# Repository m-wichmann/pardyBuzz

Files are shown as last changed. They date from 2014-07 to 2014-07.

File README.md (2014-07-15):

# pardyBuzz
This is a little hardware, that attaches a button to USB using an ATtiny. Instead of hardware USB this project uses the software USB stack V-USB [1]. Basically the whole project is based on the info from the V-USB site.

This project is developed as input for the pyPardy project [2].

# License
The firmware is licensed under GPLv3. The hardware is licensed under TAPR Open Hardware License.

[1] http://www.obdev.at/vusb/
[2] https://github.com/wichmann/pyPardy

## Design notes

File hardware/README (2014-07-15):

# pardyBuzz Hardware
This is a simple PCB that contains a ATtiny and the USB interface. A button should be soldered to the PB2 pin, since thats the interrupt pin.

# BOM
* 1x ATtiny25/45/85 (tested with ATtiny85)
* 1x 100 nF
* 2x 68 Ohm
* 1x 1.5K Ohm
* 2x 3.6 V Zener Diode

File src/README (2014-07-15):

# pardyBuzz Firmware
This firmware basically just uses the V-USB stack and the INT0 Interrupt.

The buzzer implements a USB control endpoint, as well as an interrupt endpoint. The control endpoint is used to get and set the device id (bRequest == 0). Reading of the device id is done by sending the parameter 0x00. Every other value sets the id to that value. The interrupt endpoint is used to signal a button push. Everytime the button interrupt occurs, the byte 0xa5 is send over this endpoint. Debouncing is not done in the firmware.

Since the internal oscillator is used, calibration is used to optimize the USB timing. The function 'calibrateOscillator' is taken from some V-USB sample projects.

# EEPROM
1   -> Oscillator calibration
2   -> Device ID

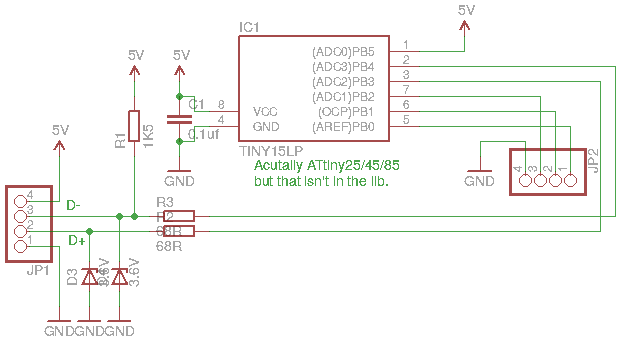
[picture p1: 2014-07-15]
hardware/circuit.png

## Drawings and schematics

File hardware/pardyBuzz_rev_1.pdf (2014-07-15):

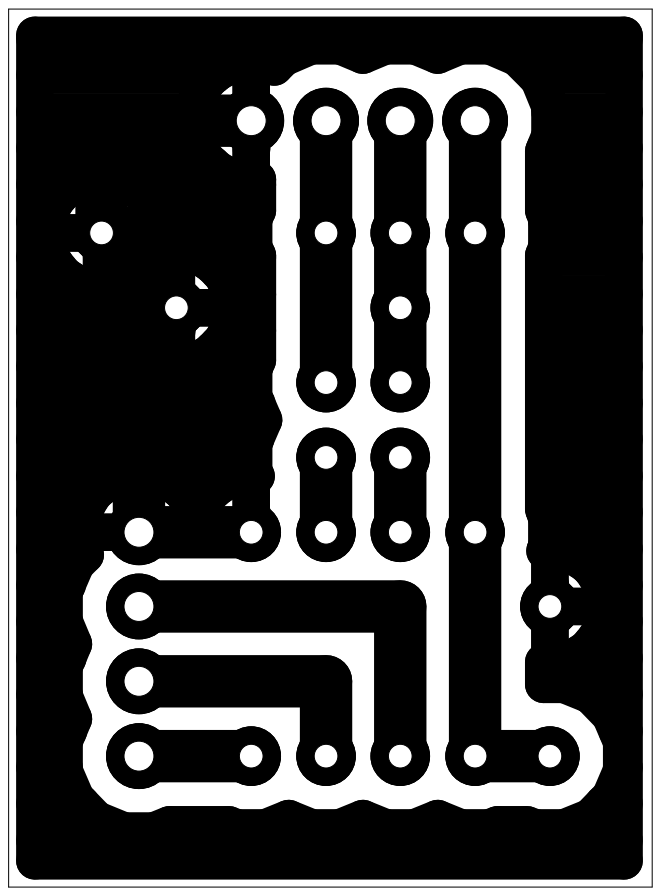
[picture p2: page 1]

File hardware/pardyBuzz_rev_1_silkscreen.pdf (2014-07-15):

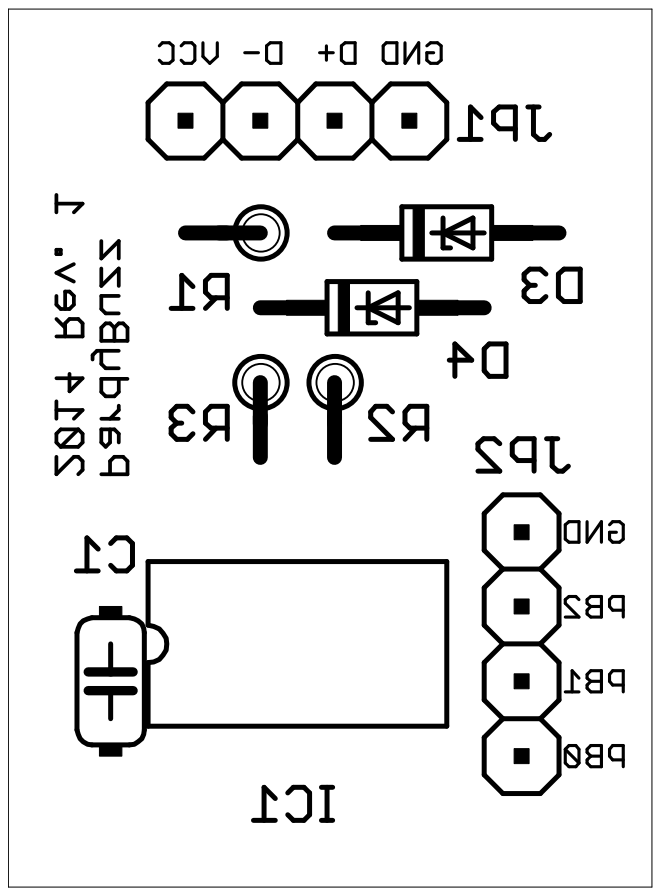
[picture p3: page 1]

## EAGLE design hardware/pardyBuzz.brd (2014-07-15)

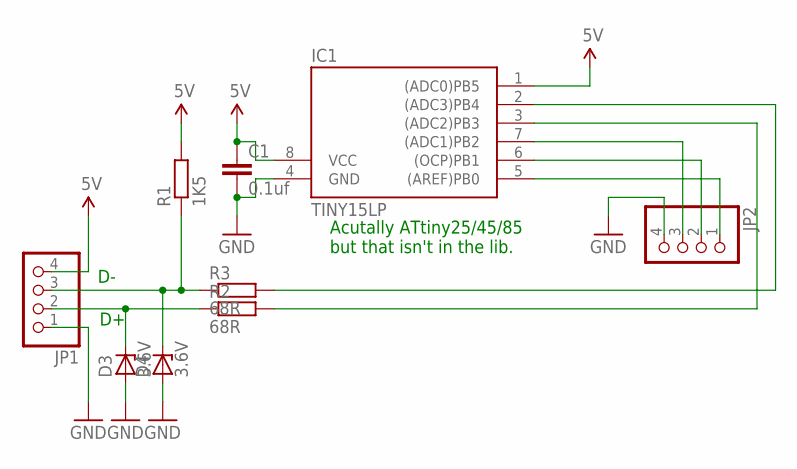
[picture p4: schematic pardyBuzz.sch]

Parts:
C1: 0.1uf; C050-024X044
D3, D4: 3.6V; DO34Z7
IC1: TINY15LP; DIL08
JP1, JP2: PINHD-1X4; 1X04
R1: 1K5; 0204V
R2, R3: 68R; 0204V

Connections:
5V: C1.1, IC1.1 ((ADC0)PB5), IC1.8 (VCC), JP1.4, R1.2
GND: C1.2, D3.A, D4.A, IC1.4 (GND), JP1.1, JP2.4
unnamed: IC1.3 ((ADC2)PB3), R2.2
unnamed: D4.C, JP1.3, R1.1, R3.1
unnamed: D3.C, JP1.2, R2.1
unnamed: IC1.7 ((ADC1)PB2), JP2.3
unnamed: IC1.6 ((OCP)PB1), JP2.2
unnamed: IC1.2 ((ADC3)PB4), R3.2
unnamed: IC1.5 ((AREF)PB0), JP2.1

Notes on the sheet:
Acutally ATtiny25/45/85 but that isn't in the lib.

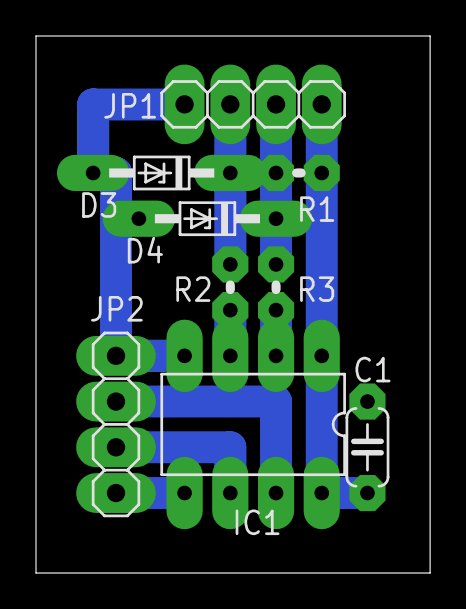
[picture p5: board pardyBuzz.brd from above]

Board: 2 copper layers, 21.9 x 29.8 mm, 9 parts (0 on the bottom side), 9 nets.

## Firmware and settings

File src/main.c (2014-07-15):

#include <avr/interrupt.h>
#include <avr/eeprom.h>
#include <util/delay.h>
#include "usbdrv.h"
#include "osc_cal.h"

/*
 * TOOD:
 * - Watchdog? Brownout?
 */

/*
 * PB0: MOSI (ISP)
 * PB1: MISO (ISP)
 * PB2: SCK (ISP) / Button
 * PB3: D-
 * PB4: D+
 * PB5: RESET (ISP)
 */

#define EEPROM_ADDR_DEVICE_ID       ((uint8_t *) 1)
uint8_t device_id = 0x00;

usbMsgLen_t usbFunctionSetup(uchar data[8])
{
    usbRequest_t *rq = (void *)data;
    static uchar replyBuf[1];

    usbMsgPtr = (usbMsgPtr_t) replyBuf;
    if(rq->bRequest == 0){      /* Get/Set Device ID */
        /* Reserved id 0x00 is used to just read the id.
         * All other values set the device id.
         */
        if (rq->wValue.bytes[0] != 0x00)
        {
            device_id = rq->wValue.bytes[0]; 
        	eeprom_update_byte(EEPROM_ADDR_DEVICE_ID, device_id);
        }
        replyBuf[0] = device_id;
        return 1;
    }

    return 0;
}


/**
 * Button interrupt.
 * Debouncing is realized through USB (poll interval 25ms).
 * Everything else can be done later in software.
 */
ISR (INT0_vect)
{
    static uchar data[1] = {0xa5};  /* marker 0xa5 to detect transmission problems. */

    /* Just update the interrupt data, regardless of current transferstate.
     * Either the data is overwritten, or another interrupt is send.
     */
    usbSetInterrupt(data, 1);

    GIMSK |= (1 << INTF0);
}



int main(void)
{
    /* read device id */
    device_id = eeprom_read_byte(EEPROM_ADDR_DEVICE_ID);

    /* Button with pull up */
    DDRB  &= ~(1 << PB2);
    PORTB |=  (1 << PB2);

    /* Some flank interrupt of the button. */
    MCUCR &= ~(1 << ISC00);
    MCUCR |= (1 << ISC01);
    GIMSK |= (1 << INTF0);

    usbInit();

    usbDeviceDisconnect();
    _delay_ms(500.0);
    usbDeviceConnect();

    sei();

    for(;;){    /* main event loop */
        usbPoll();
    }

    return 0;
}

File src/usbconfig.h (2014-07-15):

/* Name: usbconfig.h
 * Project: V-USB, virtual USB port for Atmel's(r) AVR(r) microcontrollers
 * Author: Christian Starkjohann
 * Creation Date: 2005-04-01
 * Tabsize: 4
 * Copyright: (c) 2005 by OBJECTIVE DEVELOPMENT Software GmbH
 * License: GNU GPL v2 (see License.txt), GNU GPL v3 or proprietary (CommercialLicense.txt)
 */

#ifndef __usbconfig_h_included__
#define __usbconfig_h_included__


/*
General Description:
This file is an example configuration (with inline documentation) for the USB
driver. It configures V-USB for USB D+ connected to Port D bit 2 (which is
also hardware interrupt 0 on many devices) and USB D- to Port D bit 4. You may
wire the lines to any other port, as long as D+ is also wired to INT0 (or any
other hardware interrupt, as long as it is the highest level interrupt, see
section at the end of this file).
+ To create your own usbconfig.h file, copy this file to your project's
+ firmware source directory) and rename it to "usbconfig.h".
+ Then edit it accordingly.
*/

/* ---------------------------- Hardware Config ---------------------------- */

#define USB_CFG_IOPORTNAME      B
/* This is the port where the USB bus is connected. When you configure it to
 * "B", the registers PORTB, PINB and DDRB will be used.
 */
#define USB_CFG_DMINUS_BIT      3
/* This is the bit number in USB_CFG_IOPORT where the USB D- line is connected.
 * This may be any bit in the port.
 */
#define USB_CFG_DPLUS_BIT       4
/* This is the bit number in USB_CFG_IOPORT where the USB D+ line is connected.
 * This may be any bit in the port. Please note that D+ must also be connected
 * to interrupt pin INT0! [You can also use other interrupts, see section
 * "Optional MCU Description" below, or you can connect D- to the interrupt, as
 * it is required if you use the USB_COUNT_SOF feature. If you use D- for the
 * interrupt, the USB interrupt will also be triggered at Start-Of-Frame
 * markers every millisecond.]
 */
#define USB_CFG_CLOCK_KHZ       (F_CPU/1000)
/* Clock rate of the AVR in kHz. Legal values are 12000, 12800, 15000, 16000,
 * 16500, 18000 and 20000. The 12.8 MHz and 16.5 MHz versions of the code
 * require no crystal, they tolerate +/- 1% deviation from the nominal
 * frequency. All other rates require a precision of 2000 ppm and thus a
 * crystal!
 * Since F_CPU should be defined to your actual clock rate anyway, you should
 * not need to modify this setting.
 */
#define USB_CFG_CHECK_CRC       0
/* Define this to 1 if you want that the driver checks integrity of incoming
 * data packets (CRC checks). CRC checks cost quite a bit of code size and are
 * currently only available for 18 MHz crystal clock. You must choose
 * USB_CFG_CLOCK_KHZ = 18000 if you enable this option.
 */

/* ----------------------- Optional Hardware Config ------------------------ */

/* #define USB_CFG_PULLUP_IOPORTNAME   D */
/* If you connect the 1.5k pullup resistor from D- to a port pin instead of
 * V+, you can connect and disconnect the device from firmware by calling
 * the macros usbDeviceConnect() and usbDeviceDisconnect() (see usbdrv.h).
 * This constant defines the port on which the pullup resistor is connected.
 */
/* #define USB_CFG_PULLUP_BIT          4 */
/* This constant defines the bit number in USB_CFG_PULLUP_IOPORT (defined
 * above) where the 1.5k pullup resistor is connected. See description
 * above for details.
 */

/* --------------------------- Functional Range ---------------------------- */
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

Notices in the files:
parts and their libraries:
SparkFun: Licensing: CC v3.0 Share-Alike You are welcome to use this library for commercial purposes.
